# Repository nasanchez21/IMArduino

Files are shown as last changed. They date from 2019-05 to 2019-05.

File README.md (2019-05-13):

# IMArduino
Repository for the development of an NYUSH IMA Barebones Arduino Uno clone kit.

The goal of this project is to develop a DIY Arduino clone kit that would allow users to manually build their own Arduino Uno clones. The value of this kit is that it has pedagogical value and can also serve as a functional replacement for standard Arduino Uno for many uses.

# Documentation

https://docs.google.com/spreadsheets/d/1-6iVScVSJgVeOGY05u6eFCvq3GYR2P5O7BafCsH0iSc/edit#gid=1137227327

# References

https://store.arduino.cc/usa/arduino-uno-rev3 (within their Documentation tab, have a set of Eagle files that we used as a reference design)

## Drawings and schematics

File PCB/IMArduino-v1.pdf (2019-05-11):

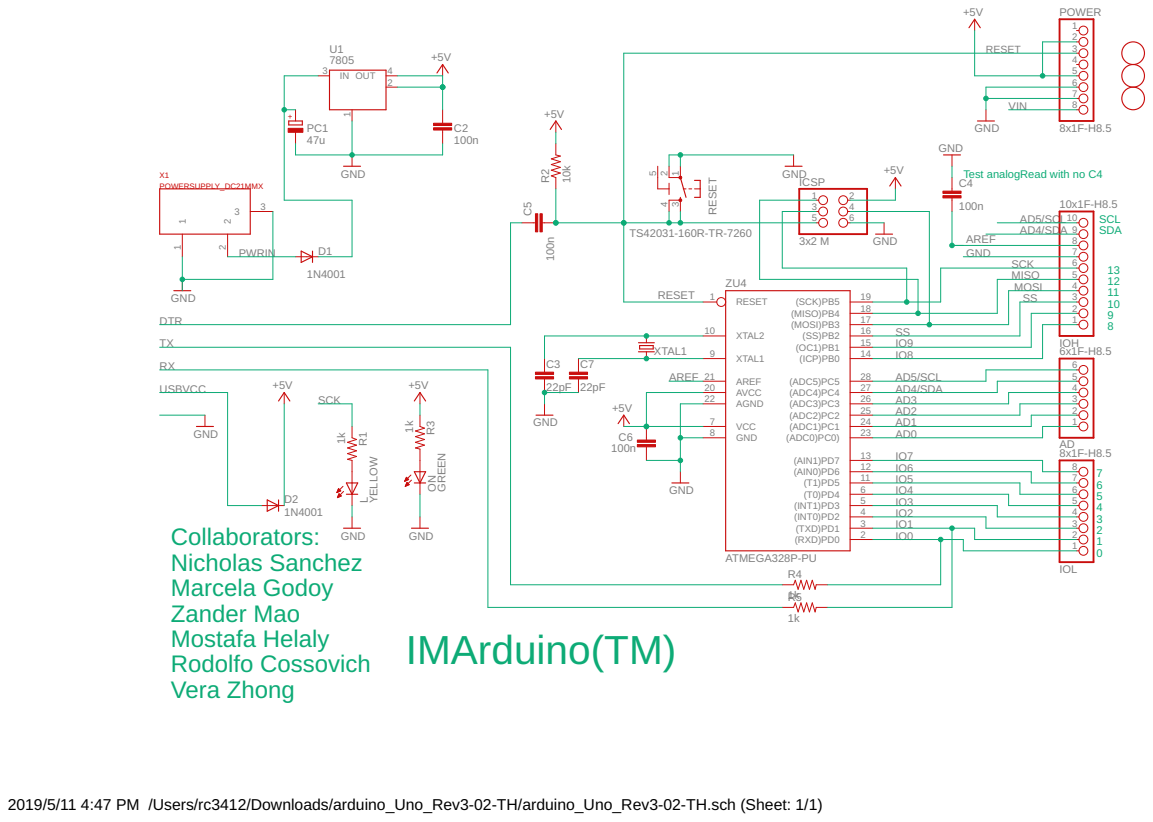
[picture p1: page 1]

Test analogRead with no C4

2019/5/11 4:47 PM /Users/rc3412/Downloads/arduino_Uno_Rev3-02-TH/arduino_Uno_Rev3-02-TH.sch (Sheet: 1/1)

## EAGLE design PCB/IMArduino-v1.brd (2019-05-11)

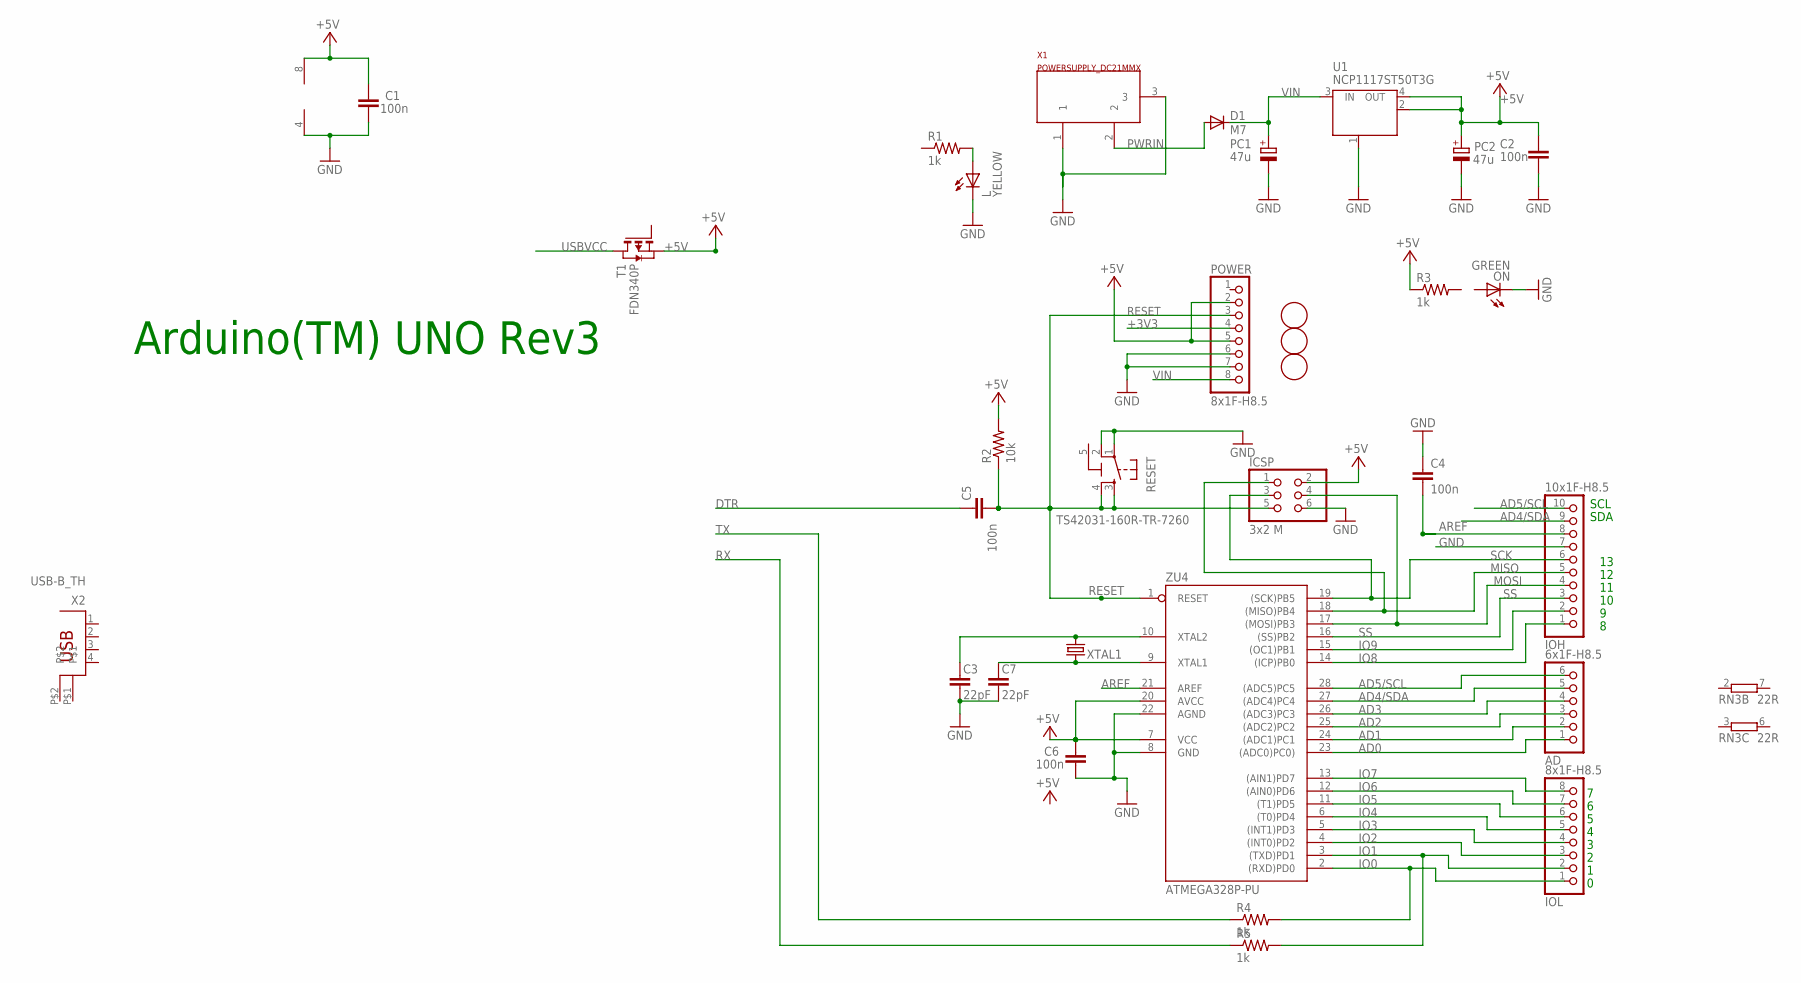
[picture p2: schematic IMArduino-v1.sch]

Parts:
AD: 6x1F-H8.5; 1X06
C1, C2, C4, C5, C6: 100n; C0603-ROUND
C3, C7: 22pF; C0603-ROUND
D1: M7; SMB
FD1, FD2, FD3: FIDUCIALMOUNT; FIDUCIA-MOUNT
ICSP: 3x2 M; 2X03
IOH: 10x1F-H8.5; 1X10
IOL: 8x1F-H8.5; 1X08
L: YELLOW; CHIP-LED0805
ON: GREEN; CHIP-LED0805
PC1, PC2: 47u; PANASONIC_D
POWER: 8x1F-H8.5; 1X08
R1, R3, R4, R5: 1k; 0204/7
R2: 10k; 0204/7
RESET: TS42031-160R-TR-7260; TS42
RN3: 22R; CAY16
T1: FDN340P; SOT-23
U1: NCP1117ST50T3G; SOT223
U5: LMV358IDGKR; MSOP08
X1: POWERSUPPLY_DC21MMX; POWERSUPPLY_DC-21MM
X2: USB-B_TH; PN61729
XTAL1: CRYSTALHC49U-V; HC49U-V
ZU4: ATMEGA328P-PU; DIL28-3

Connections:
5-GND: RESET.5 (5-GND)
+3V3: POWER.4
+5V: C1.2, C2.2, C6.2, ICSP.2, PC2.+, POWER.2, POWER.5, R2.2, R3.1, T1.2 (S), U1.2 (OUT), U1.4 (OUT), U5.8 (V+), ZU4.7 (VCC), ZU4.20 (AVCC)
AD0: AD.1, ZU4.23 ((ADC0)PC0))
AD1: AD.2, ZU4.24 ((ADC1)PC1)
AD2: AD.3, ZU4.25 ((ADC2)PC2)
AD3: AD.4, ZU4.26 ((ADC3)PC3)
AD4/SDA: AD.5, IOH.9, ZU4.27 ((ADC4)PC4)
AD5/SCL: AD.6, IOH.10, ZU4.28 ((ADC5)PC5)
AREF: C4.2, IOH.8, ZU4.21 (AREF)
DTR: C5.1
GND: C1.1, C2.1, C3.1, C4.1, C6.1, C7.1, ICSP.6, IOH.7, L.C, ON.C, PC1.-, PC2.-, POWER.6, POWER.7, RESET.1, RESET.2, U1.1 (GND/ADJ), U5.4 (V-), X1.1, X1.3, ZU4.8 (GND), ZU4.22 (AGND)
IO0: IOL.1, R4.2, ZU4.2 ((RXD)PD0)
IO1: IOL.2, R5.2, ZU4.3 ((TXD)PD1)
IO2: IOL.3, ZU4.4 ((INT0)PD2)
IO3: IOL.4, ZU4.5 ((INT1)PD3)
IO4: IOL.5, ZU4.6 ((T0)PD4)
IO5: IOL.6, ZU4.11 ((T1)PD5)
IO6: IOL.7, ZU4.12 ((AIN0)PD6)
IO7: IOL.8, ZU4.13 ((AIN1)PD7)
IO8: IOH.1, ZU4.14 ((ICP)PB0)
IO9: IOH.2, ZU4.15 ((OC1)PB1)
MISO: ICSP.1, IOH.5, ZU4.18 ((MISO)PB4)
MOSI: ICSP.4, IOH.4, ZU4.17 ((MOSI)PB3)
unnamed: L.A, R1.2
PWRIN: D1.A, X1.2
RESET: C5.2, ICSP.5, POWER.3, R2.1, RESET.3, RESET.4, ZU4.1 (RESET)
RX: R5.1
SCK: ICSP.3, IOH.6, ZU4.19 ((SCK)PB5)
SS: IOH.3, ZU4.16 ((SS)PB2)
TX: R4.1
USBVCC: T1.1 (D)
VIN: D1.C, PC1.+, POWER.8, U1.3 (IN)
XTAL1: C7.2, XTAL1.1, ZU4.9 (XTAL1)
XTAL2: C3.2, XTAL1.2, ZU4.10 (XTAL2)

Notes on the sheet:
Arduino(TM) UNO Rev3
SDA
SCL

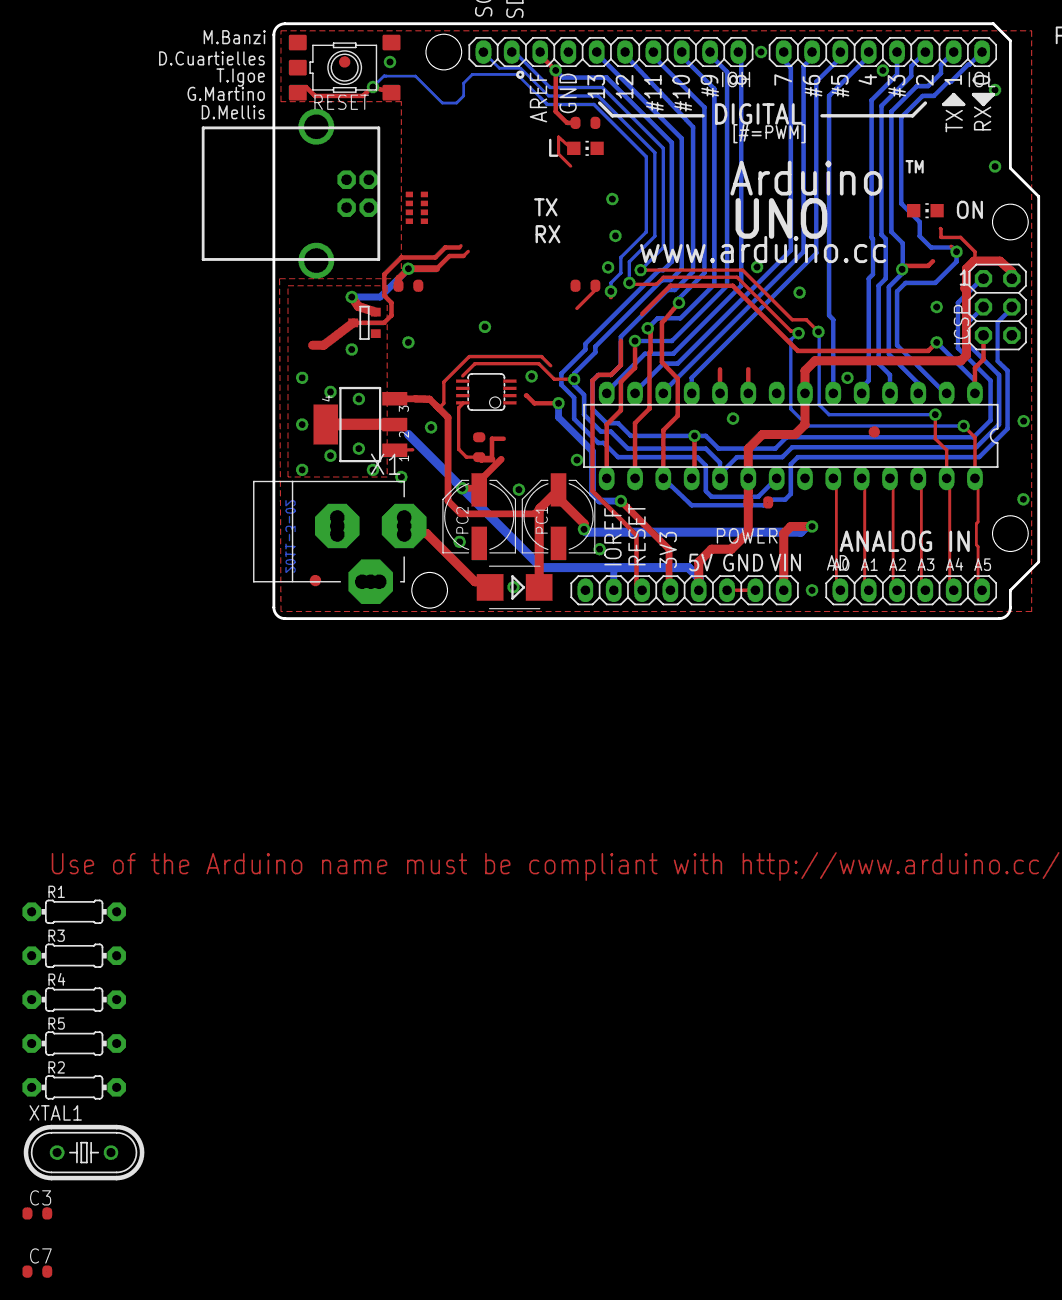
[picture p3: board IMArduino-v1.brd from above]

Board: 2 copper layers, 68.6 x 53.3 mm, 34 parts (0 on the bottom side), 29 nets.

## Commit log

2019-05-11 first design
    [IMArduino-v1.brd, IMArduino-v1.sch]
2019-05-13 7805 footprint changed to TO-220, Readme updated
